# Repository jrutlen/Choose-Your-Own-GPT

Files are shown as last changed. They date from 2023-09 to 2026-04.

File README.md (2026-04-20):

# Choose Your Own GPT

Choose Your Own GPT is a seemingly analog device without any screens or visible digital elements. Spinning the physical dials to select characters and a story setting and then hitting the large arcade 'go' button, the built-in printer will spit out a Choose Your Own Adventure type story on the built-in receipt printer.

## Features

- Built-in 58mm thermal printer to dispense stories on demand
- Designed to be printable on 200mm² 3D printers
- Top dials can be snapped off of the main PCB to allow modification to any size
- Optional 4th dial can be added to increase story objects or add an additional element (talk like a pirate, etc.)
- Support for e-ink display (untested)
- Over-the-air (OTA) firmware updates via the web portal
- Import/export configuration as JSON

## Hardware Requirements

- ESP32 development board
- 58mm thermal printer (connected to ESP32 Serial2: RX=16, TX=17)
- Adafruit NeoPixel LEDs (WaitEnd ring: 13 LEDs on pin 26; Go button: 3 LEDs on pin 33)
- Arcade-style buttons with LEDs (Red: pin 27, Blue: pin 12, Green: pin 2, Yellow: pin 15)
- Rotary dials wired to input matrix (see PCB directory for schematic)
- 3D-printed enclosure (STL files in the `STLs` directory)
- Bill of materials in `Bill of Materials.csv`

## Building and Flashing

This project uses [PlatformIO](https://platformio.org/). All library dependencies are declared in `ChooseYourOwnGPT/platformio.ini` and are fetched automatically on first build.

1. Install [PlatformIO IDE](https://platformio.org/install) or the PlatformIO CLI.
2. Open the `ChooseYourOwnGPT` folder as a PlatformIO project.
3. Build and upload to the ESP32:
   ```
   pio run --target upload
   ```
4. You do **not** need to add your API key to the code before uploading — it is set via the web portal after the device is running.

### Library Dependencies

| Library | Version |
|---|---|
| Adafruit NeoPixel | 1.12.4 |
| Adafruit Thermal Printer | 1.4.1 |
| NetWizard | 1.2.0 |
| ArduinoJson | 7.3.1 |

### Building with GitHub Actions

A workflow (`.github/workflows/build.yml`) automatically builds the firmware on every push or pull request to `main`/`master` that touches `ChooseYourOwnGPT/` or the workflow file itself. No local toolchain is required to produce a flashable binary.

**What the workflow does:**
1. Checks out the repository.
2. Installs PlatformIO via `pip`.
3. Runs `pio run` inside `ChooseYourOwnGPT/`.
4. Uploads the compiled binaries as a `firmware` artifact:
   - `firmware.bin` — application image
   - `bootloader.bin` — ESP32 bootloader
   - `partitions.bin` — partition table

**Downloading the artifact:**
1. Go to the **Actions** tab of the repository on GitHub.
2. Click the latest successful **Build Firmware** run.
3. Scroll to the **Artifacts** section at the bottom and download `firmware`.
4. Unzip the archive to get the `.bin` files.

**Flashing the downloaded firmware:**

To flash from scratch (first time or full reflash), use `esptool.py`:
```
esptool.py --chip esp32 --baud 921600 \
  write_flash \
  0x1000  bootloader.bin \
  0x8000  partitions.bin \
  0x10000 firmware.bin
```

To update an already-running device, use the OTA firmware update in the web portal — see [OTA Firmware Update](#ota-firmware-update) below.

## First-Time Setup

1. Power on the device. It will start a Wi-Fi access point named **`ChooseYourOwnGPT`** with the password **`itMightBeMagic`**.
2. Connect to that network from your phone or computer.
3. A captive portal will open automatically (or navigate to `http://192.168.4.1`).
4. Enter your home Wi-Fi credentials and save. The device will reboot and connect to your network.

## Configuration

Once the device is connected to your Wi-Fi network, open a browser and go to:

```
http://<device-ip>/config
```

The device IP is printed to the serial console on connection. The configuration portal lets you adjust all settings without reflashing.

### General Settings

| Setting | Description |
|---|---|
| **OpenAI API Key** | Your `sk-…` key from [platform.openai.com](https://platform.openai.com/api-keys). Stored on the device only — never sent anywhere except the OpenAI API. |
| **OpenAI Model** | The model to use for story generation (default: `gpt-4o`). |
| **Hyphenate long words** | When enabled, words that are too long for a line are broken with a hyphen instead of overflowing. |

### Character Names (Small Dial)

Up to **10** character names can be assigned to positions on the small dial. Each position corresponds to a dial setting (0–9). Names can include relationship context (e.g. `"Mia (a 7-year-old girl)"`), which is passed directly to the story prompt.

### Adventure Destinations (Large Dial)

Up to **16** adventure destinations can be assigned to positions on the large dial. Each entry is a sentence fragment appended to the story prompt (e.g. `" who go on an adventure in the Amazon Rainforest."`).

### Story Prompts

These fields control the text sent to the OpenAI API at each stage of the story:

| Field | Description |
|---|---|
| **Story Prompt** | Opening prompt prepended before the selected character names. |
| **Instructions** | Instructions appended after the adventure destination (formatting rules, chapter length, button options, etc.). |
| **Surprise Ending Prompt** | Sent when the red button is pressed to request an unexpected ending. |
| **Blue Button – Continue** | Message sent when the blue button is pressed to continue the story. |
| **Blue Button – Final Chapter** | Message sent when the blue button is pressed in the final chapter. |
| **Yellow Button – Continue** | Message sent when the yellow button is pressed to continue the story. |
| **Yellow Button – Final Chapter** | Message sent when the yellow button is pressed in the final chapter. |

### Import / Export

Use the **Export Settings JSON** button to download all current settings as a `cyogpt-config.json` file. Use **Import Settings JSON** to restore or share a configuration.

### OTA Firmware Update

The `/config` portal includes a firmware update section. Select a compiled `.bin` file (from `pio run` build output) and click **Upload Firmware**. The device will reboot automatically after a successful update.

## Usage

1. Power on the device and wait for it to connect to Wi-Fi (the LEDs will indicate status).
2. Spin the **small dial** to select a character and the **large dial** to choose an adventure destination.
3. Press the **green Go button** to generate a story. The printer will output the first chapter.
4. At the end of each chapter, press the **blue** or **yellow** button to choose how the story continues.
5. Press the **red button** at any point to trigger a surprise ending.
6. After the final (5th) chapter, the story is complete. Set the dials and press Go to start a new story.

## Related

Build log with photos

[Hackaday.io](https://hackaday.io/project/192751-choose-your-own-gpt)

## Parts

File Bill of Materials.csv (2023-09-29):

Designator | Quantity | Designation
1,20 | 2 | PinSocket_1x19_P2.54mm_Vertical
D1-D12 | 12 | LED 3mm
D13-D32 | 20 | 1N4148
J1,J3,J13 | 3 | JST_XH_B3B-XH-A_1x03_P2.50mm_Vertical
J2,J4,J5,J6,J7,J8,J9,J10,J11,J12 | 10 | JST_XH_B2B-XH-A_1x02_P2.50mm_Vertical
J14 | 1 | JST_XH_B5B-XH-A_1x05_P2.50mm_Vertical
Q1-Q7 | 7 | 2N2222
R1,R3,R5 | 3 | 22Ω
R2,R11,R16 | 3 | 390Ω
R4,R6,R12,R14 | 4 | 1.7kΩ
R13,R15,R17 | 3 | 4.7kΩ
R7-R10 | 4 | Button LED Resistors (Optional - Bridge JP1&JP2 to bypass)
SW1-SW3 | 3 | Nidec_Copal_SH-7010C
SW5-SW8 | 4 | Magnetic Reed Switch (Optional)

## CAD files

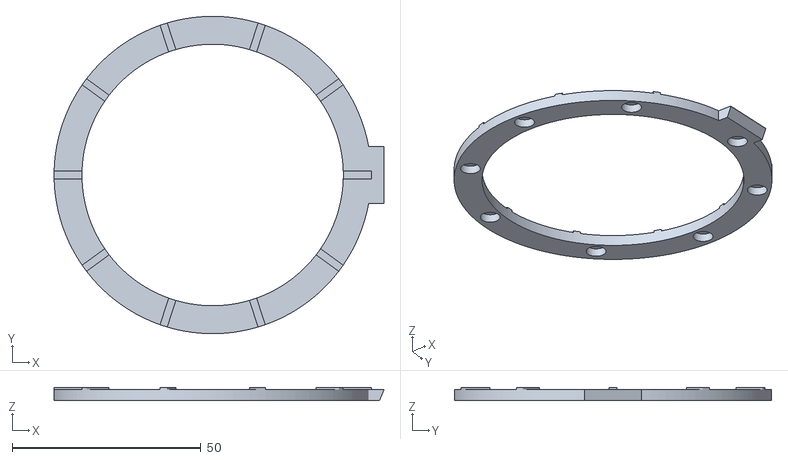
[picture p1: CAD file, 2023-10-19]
STLs/Ring Right Raised.stl
87.4 x 84.0 x 3.50

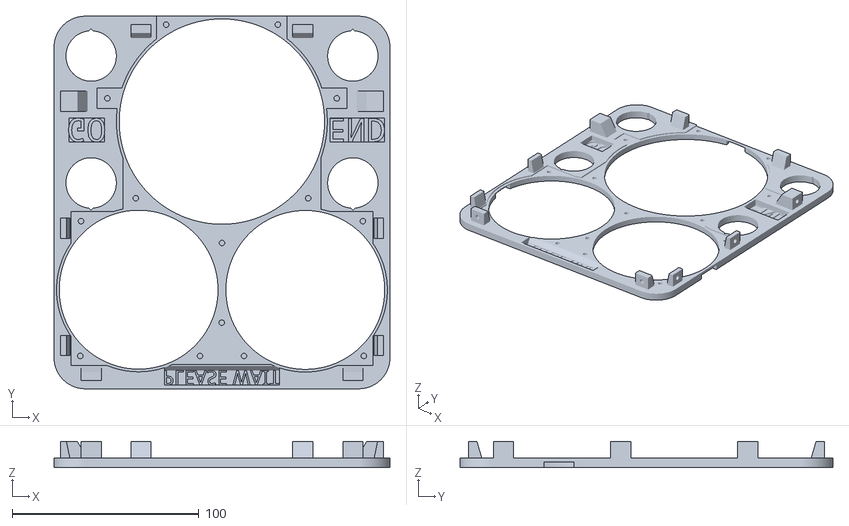
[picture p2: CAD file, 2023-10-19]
STLs/Front Panel Frame.stl
180.0 x 199.6 x 14.0

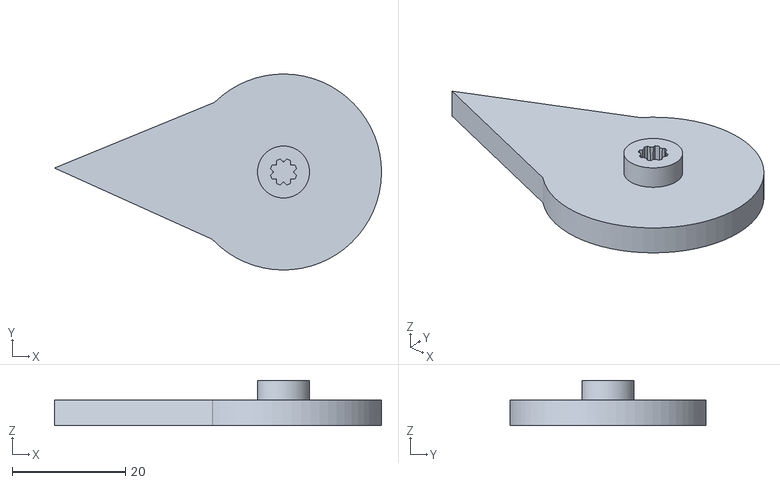
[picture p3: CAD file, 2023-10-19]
STLs/Dial Large.stl
57.8 x 34.6 x 8.00

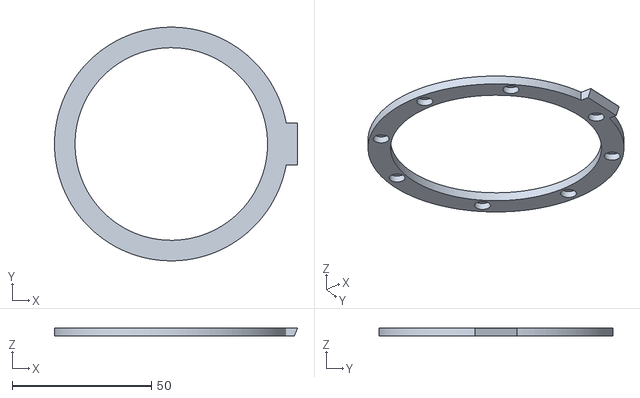
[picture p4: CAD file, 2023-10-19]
STLs/Ring Right Flat.stl
87.4 x 84.0 x 3.00

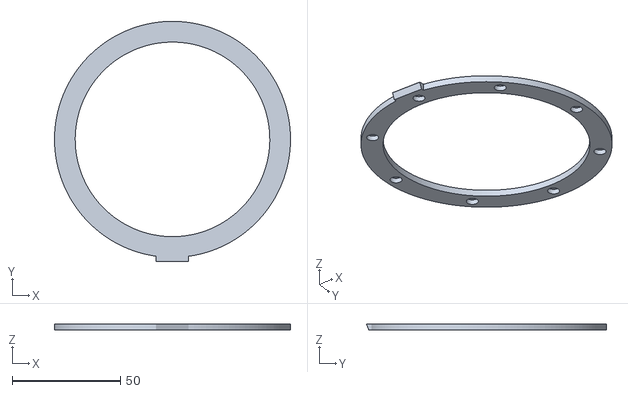
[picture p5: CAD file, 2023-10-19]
STLs/Ring Bottom Flat.stl
109.0 x 110.9 x 3.00

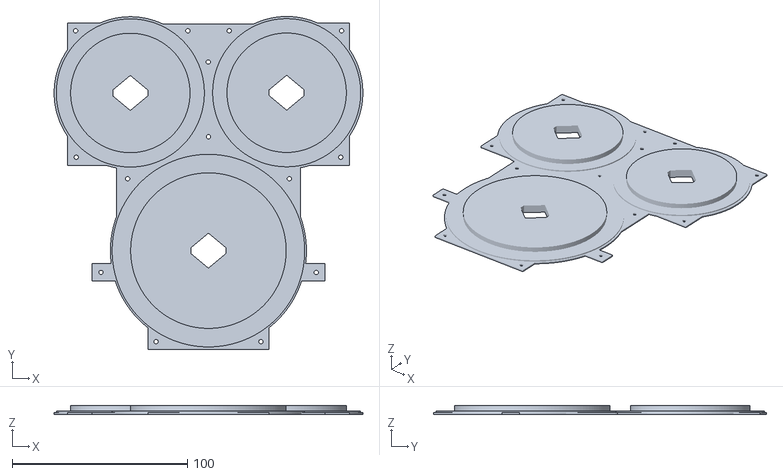
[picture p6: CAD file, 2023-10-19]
STLs/Front Panel Insert.stl
176.3 x 190.2 x 5.00

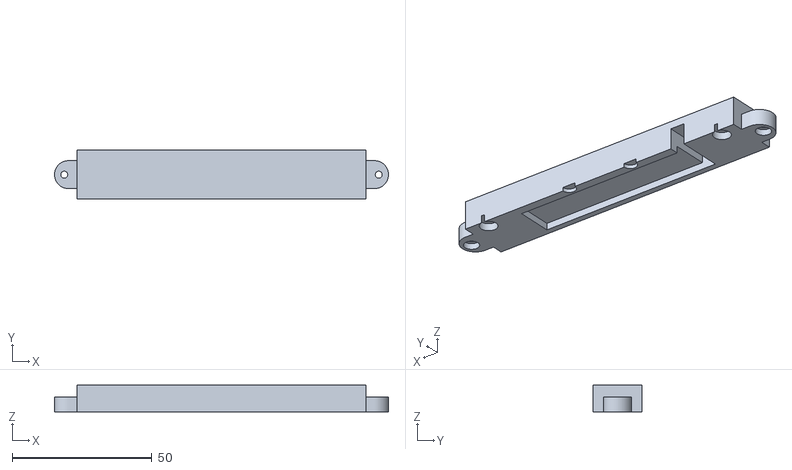
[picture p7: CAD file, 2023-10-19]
STLs/Bridge Insert.stl
119.6 x 17.6 x 9.58

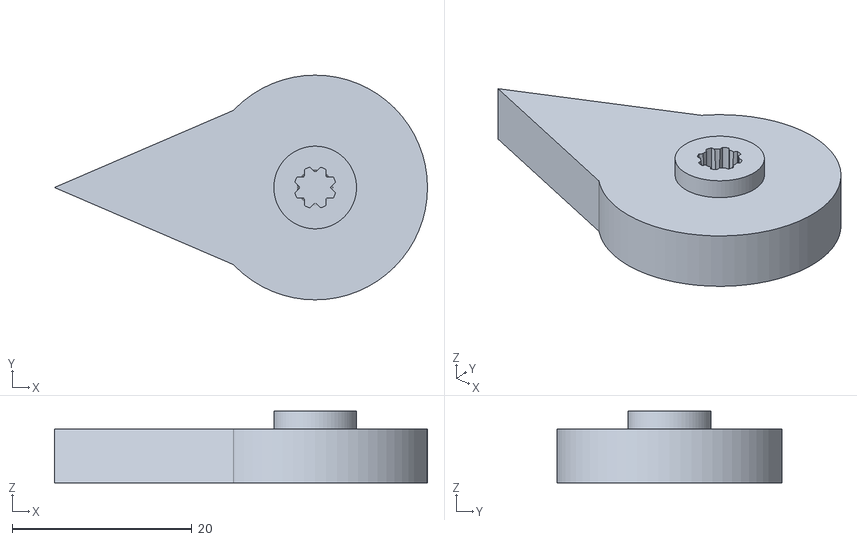
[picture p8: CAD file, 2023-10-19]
STLs/Dial Small.stl
41.5 x 25.0 x 8.00

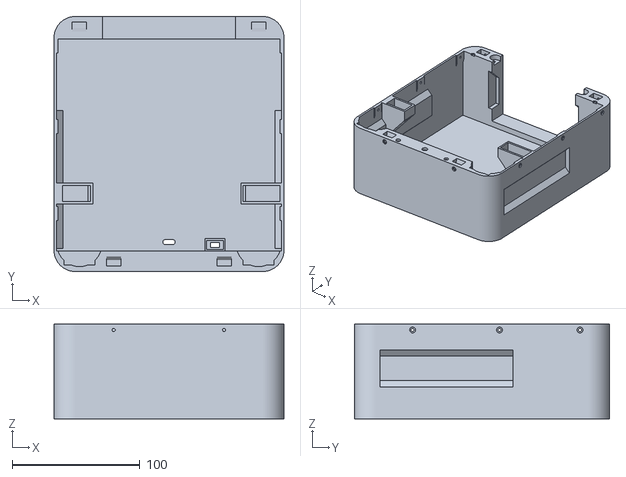
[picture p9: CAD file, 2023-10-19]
STLs/Body.stl
180.0 x 199.6 x 74.0

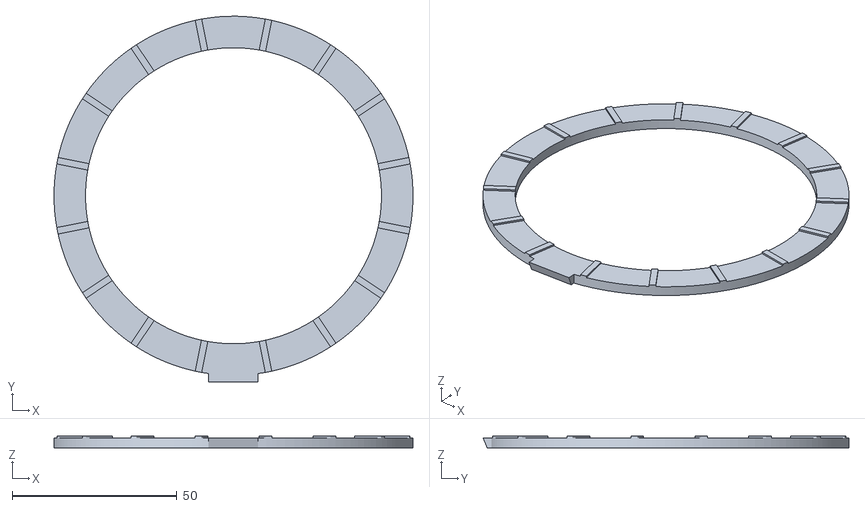
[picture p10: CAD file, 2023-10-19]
STLs/Ring Bottom Raised.stl
109.0 x 110.9 x 3.50

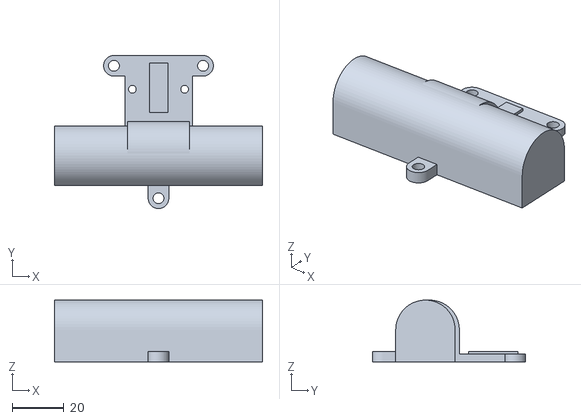
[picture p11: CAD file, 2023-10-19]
STLs/18650 Holder.stl
80.5 x 59.2 x 23.9

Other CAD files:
STLs/Ring Left Raised.stl
STLs/Ring Left Flat.stl
STLs/Body USB Only.stl

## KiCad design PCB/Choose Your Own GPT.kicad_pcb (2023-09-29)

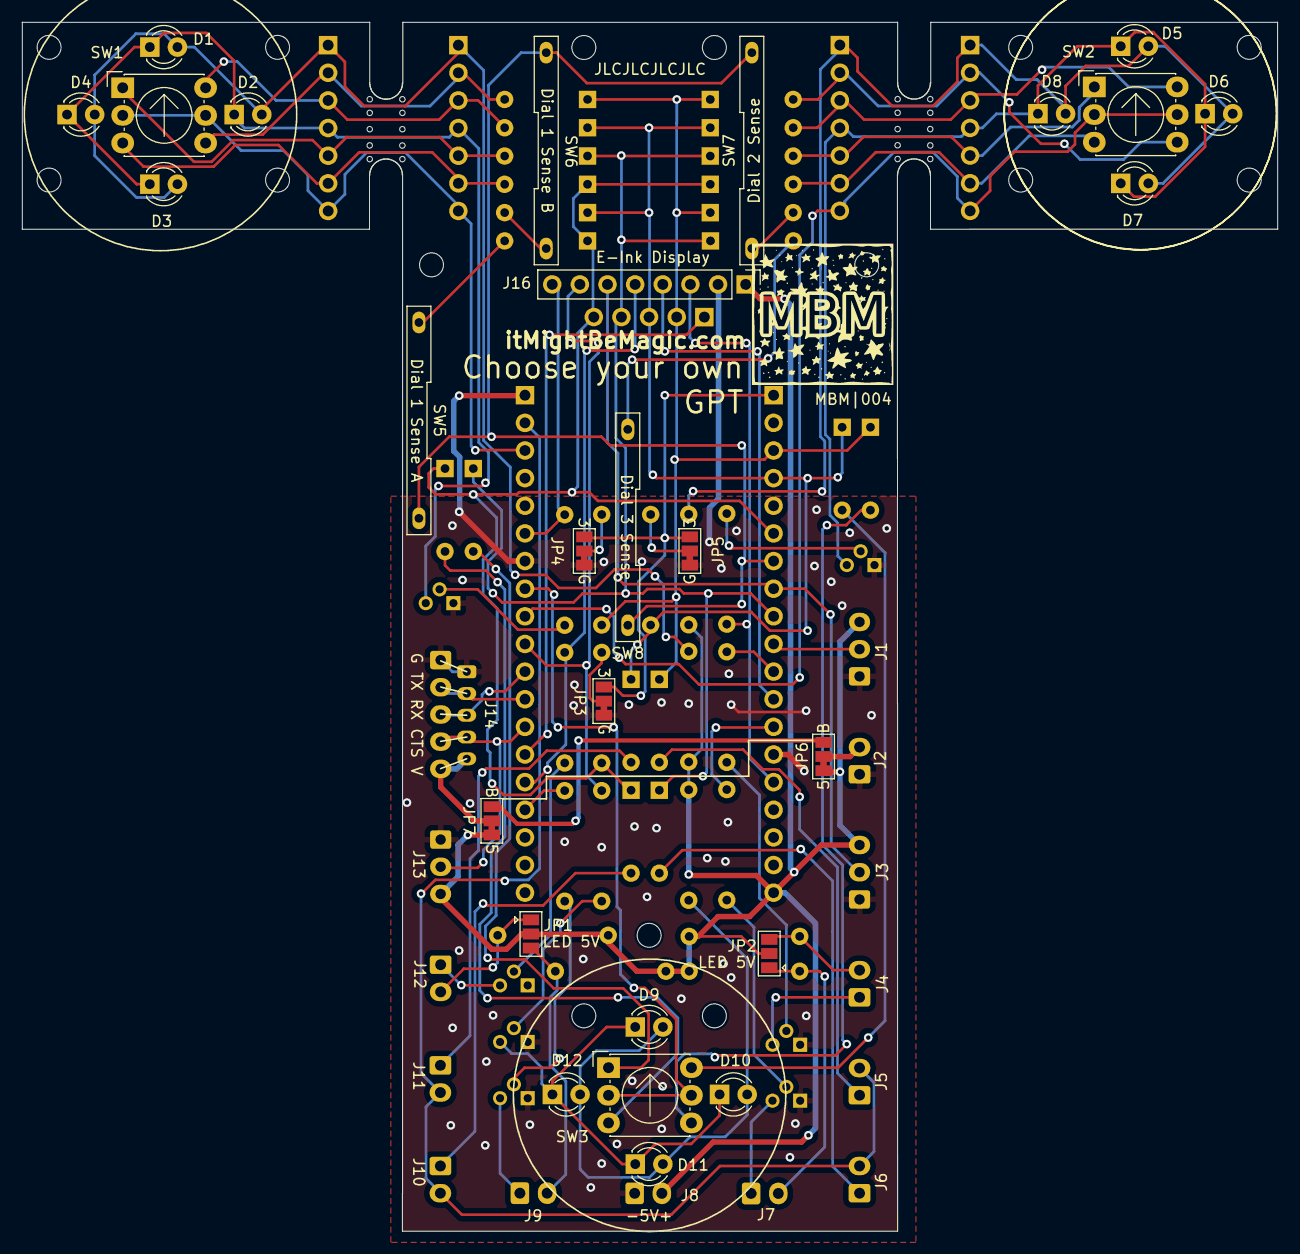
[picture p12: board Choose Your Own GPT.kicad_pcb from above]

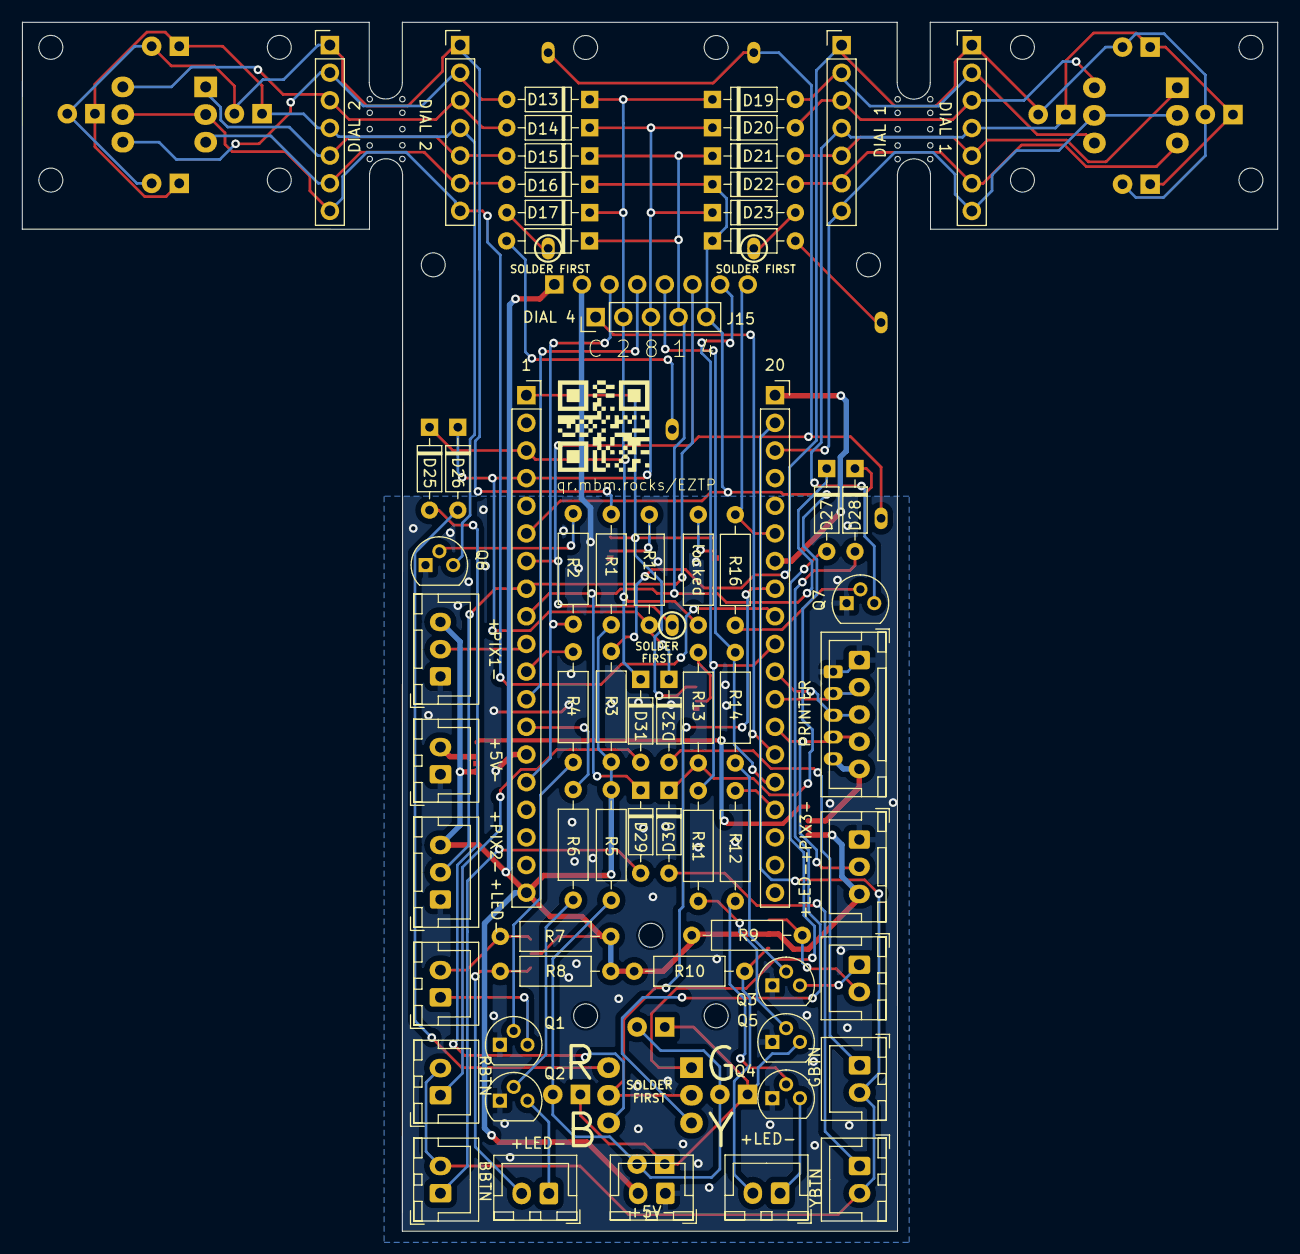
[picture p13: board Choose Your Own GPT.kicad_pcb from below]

Board: 2 copper layers, 115.4 x 111.1 mm, 97 parts (67 on the bottom side), 35 nets.

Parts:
1, 20: PinSocket_1x19_P2.54mm_Vertical
D1, D2, D3, D4, D5, D6, D7, D8, D9, D10, D11, D12: LED_D3.0mm
D13, D14, D15, D16, D17, D18, D19, D20, D21, D22, D23, D24, D25, D26, D27, D28, D29, D30, D31, D32: D_DO-35_SOD27_P7.62mm_Horizontal
DIAL 1, DIAL 1#2, DIAL 2, DIAL 2#2: PinHeader_1x07_P2.54mm_Vertical
J1, J3, J13: JST_XH_B3B-XH-A_1x03_P2.50mm_Vertical
J2, J4, J5, J6, J7, J8, J9, J10, J11, J12: JST_XH_B2B-XH-A_1x02_P2.50mm_Vertical
J14: JST_PH_B5B-PH-K_1x05_P2.00mm_Vertical
J14#2: JST_XH_B5B-XH-A_1x05_P2.50mm_Vertical
J15: PinHeader_1x05_P2.54mm_Vertical
J16: PinHeader_1x08_P2.54mm_Vertical
JP1, JP2: SolderJumper-3_P1.3mm_Open_Pad1.0x1.5mm
JP3, JP4: SolderJumper-3_P1.3mm_Bridged12_Pad1.0x1.5mm_NumberLabels
JP5, JP6, JP7: SolderJumper-3_P1.3mm_Bridged12_Pad1.0x1.5mm_Numb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; SolderJumper-3_P1.3mm_Bridged12_Pad1.0x1.5mm_NumberLabels
MBM|004: MBM Logo
Q1, Q2, Q3, Q4, Q5, Q6, Q7: TO-92
R1, R3, R5: 22; R_Axial_DIN0207_L6.3mm_D2.5mm_P10.16mm_Horizontal
R2, R11, R16: 390; R_Axial_DIN0207_L6.3mm_D2.5mm_P10.16mm_Horizontal
R4, R6, R12, R14: 1.7k; R_Axial_DIN0207_L6.3mm_D2.5mm_P10.16mm_Horizontal
R7, R8, R9, R10: R_Axial_DIN0207_L6.3mm_D2.5mm_P10.16mm_Horizontal
R13, R17: 4.7k; R_Axial_DIN0207_L6.3mm_D2.5mm_P10.16mm_Horizontal
SW1, SW2, SW3: Nidec_Copal_SH-7010C
SW5, SW6, SW7, SW8: Magnetic Reed Switch
locked: 4.7k; R_Axial_DIN0207_L6.3mm_D2.5mm_P10.16mm_Horizontal
mouse-bite-3mm-slot, mouse-bite-3mm-slot#2: VAL**; My MouseBite
qr.mbm.rocks/EZTP: LOGO

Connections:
3v3: 1.1, JP3.3, JP4.3, JP5.3
5V: 1.19, J1.3, J2.2, J3.3, J8.2, J13.3, J14.5, J14#2.5, J16.1, JP1.2, JP2.2, JP6.1, JP6.2, JP7.1, JP7.2, R1.2, R3.2, R5.1, R7.2, R8.2, R9.1, R10.1
BLED: 1.12, Q2.2, R6.1, R6.2
BLL-: J7.1, Q2.3
BTNC: 20.23, J5.2, J6.2, J10.2, J11.2
D1C: 20.22, DIAL 1.7, DIAL 1#2.7, SW1.C
D1GND: D1.1, D2.1, D3.1, D4.1, DIAL 1.4, DIAL 1#2.4, Q7.3
D1LED: 20.21, J16.BUSY, Q7.2, R16.1, R16.2
D2C: 20.18, DIAL 2.7, DIAL 2#2.7, SW2.C
D2GND: D5.1, D6.1, D7.1, D8.1, DIAL 2.4, DIAL 2#2.4, Q6.3
D2LED: 1.13, J16.MOSI, Q6.2, R2.1, R2.2
D3C: 20.19, SW3.C
D3GND: D9.1, D10.1, D11.1, D12.1, Q5.3
D3LED: 20.5, J16.RST, Q5.2, R11.1, R11.2
D3SEN: 1.14, J16.SCK
D4C: 20.0, J15.1
DSC: 1.32, SW5.2, SW6.2, SW7.2, SW8.2
GLED: 20.15, J16.CS, Q3.2, R14.1, R14.2
GND: 20.1, 20.7, J1.1, J2.1, J3.1, J8.1, J13.1, J14.1, J14#2.1, J16.2, JP3.1, JP4.1, JP5.1, Q1.1, Q2.1, Q3.1, Q4.1, Q5.1, Q6.1, Q7.1
GNL-: J12.1, Q3.3
JUMP: JP6.3, JP7.3
LED+: D1.2, D2.2, D3.2, D5.2, D6.2, D7.2, D9.2, D10.2, D11.2, DIAL 1.1, DIAL 1#2.1, DIAL 2.1, DIAL 2#2.1, J4.2, J7.2, J9.2, J12.2, JP1.1, JP1.3, JP2.1, JP2.3, R1.1, R3.1, R5.2, R7.1, R8.1, R9.2, R10.2
NEO1: 1.26, J1.2
NEO2: 1.33, J3.2, J16.DC
NEO3: 20.4, J13.2, J14.4, J14#2.4
RDL-: J4.1, Q1.3
RLED: 1.27, Q1.2, R4.1, R4.2
RX2: 20.17, J14.3, J14#2.3
SEL1: 1.25, D15.1, D15.2, D18.1, D18.2, D21.1, D21.2, D27.1, D27.2, D29.1, D29.2, DIAL 1.5, DIAL 1#2.5, DIAL 2.5, DIAL 2#2.5, J6.1, J15.4, SW1.1, SW2.1, SW3.1, SW8.1
SEL2: 1.36, D13.1, D13.2, D17.1, D17.2, D19.1, D19.2, D25.1, D25.2, D31.1, D31.2, DIAL 1.2, DIAL 1#2.2, DIAL 2.2, DIAL 2#2.2, J5.1, J15.2, JP4.2, SW1.2, SW2.2, SW3.2, SW7.1, locked.1, locked.2
SEL4: 1.35, D16.1, D16.2, D22.1, D22.2, D24.1, D24.2, D28.1, D28.2, D30.1, D30.2, DIAL 1.6, DIAL 1#2.6, DIAL 2.6, DIAL 2#2.6, J10.1, J15.5, JP3.2, R13.1, R13.2, SW1.4, SW2.4, SW3.4, SW5.1
SEL8: 1.39, D14.1, D14.2, D20.1, D20.2, D23.1, D23.2, D26.1, D26.2, D32.1, D32.2, DIAL 1.3, DIAL 1#2.3, DIAL 2.3, DIAL 2#2.3, J11.1, J15.3, JP5.2, R17.1, R17.2, SW1.8, SW2.8, SW3.8, SW6.1
TX2: 20.16, J14.2, J14#2.2
YLED: 20.2, Q4.2, R12.1, R12.2
YWL-: J9.1, Q4.3

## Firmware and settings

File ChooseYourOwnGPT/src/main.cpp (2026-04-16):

// WiFi and Web
#include <Arduino.h>
#include <WebServer.h>
#include <NetWizard.h>
#include <memory>

// Hardware
#include <Wire.h>
#include <Adafruit_NeoPixel.h>
#include "Adafruit_Thermal.h"

// OpenAI API
#define SERVER_RESPONSE_WAIT_TIME (30 * 1000)
#include <ChatGPTuino.h>

// Configuration and Web Portal
#include "config.h"
#include "web_portal.h"

// ─── OpenAI Chat ────────────────────────────────────────────
static const int TOKENS = 750;
static const int NUM_MESSAGES = 14;
std::unique_ptr<ChatGPTuino> chat = std::make_unique<ChatGPTuino>(TOKENS, NUM_MESSAGES);

// ─── Networking ─────────────────────────────────────────────
WebServer server(80);
NetWizard NW(&server);

// ─── Application Configuration ──────────────────────────────
AppConfig appConfig;

// ─── Hardware: LEDs ─────────────────────────────────────────
Adafruit_NeoPixel WaitEnd(13, 26, NEO_GRB + NEO_KHZ800);
Adafruit_NeoPixel Go(3, 33, NEO_GRB + NEO_KHZ800);

// ─── Hardware: Thermal Printer ──────────────────────────────
Adafruit_Thermal printer(&Serial2, 4);

// ─── Pin Definitions: Button LEDs ───────────────────────────
static const int PIN_LED_RED    = 27;
static const int PIN_LED_BLUE   = 12;
static const int PIN_LED_GREEN  = 2;
static const int PIN_LED_YELLOW = 15;

// ─── Pin Definitions: Dial LEDs ─────────────────────────────
static const int PIN_DIAL_LED1 = 21;
static const int PIN_DIAL_LED2 = 13;
static const int PIN_DIAL_LED3 = 5;

// ─── Pin Definitions: Input Matrix Columns ──────────────────
static const int PIN_SCAN_1 = 25;  // Dial 3
static const int PIN_SCAN_2 = 36;  // Dial 2
static const int PIN_SCAN_4 = 35;  // Dial 1A
static const int PIN_SCAN_8 = 39;  // Dial 1B

// ─── Pin Definitions: Input Matrix Rows ─────────────────────
static const int PIN_COM_D0  = 22;
static const int PIN_COM_D1  = 18;
static const int PIN_COM_D2  = 19;
static const int PIN_COM_BTN = 23;
static const int PIN_COM_MAG = 32;

// ─── WaitEnd LED Segments ───────────────────────────────────
static const int WAIT_START  = 0;
static const int WAIT_LENGTH = 9;
static const int END_START   = 9;
static const int END_LENGTH  = 4;

// ─── PWM Configuration ─────────────────────────────────────
static const int PWM_FREQ         = 5000;
static const int PWM_CHANNEL_DIAL = 0;
static const int PWM_CHANNEL_BTN  = 1;
static const int PWM_RESOLUTION   = 8;

// ─── Matrix Scanning ───────────────────────────────────────
static const int SCAN_DELAY_MS = 100;
static const int DIAL_READ_DELAY_MS = 10;  // Settle time between sequential dial reads
unsigned long lastScanTime = 0;

int  dial[3]     = {0, 0, 0};
int  lastDial[3] = {0, 0, 0};
bool dialSet[3]  = {false, false, false};
bool button[4]   = {false, false, false, false};

// ─── State Machine ─────────────────────────────────────────
//  0 = boot
//  1 = connecting to WiFi
//  2 = connected to WiFi
//  3 = initializing (reading initial dial positions)
//  4 = ready / waiting for dial input
//  5 = story requested (first chapter transition)
//  6 = generating first chapter
//  8 = generating next chapter
//  9 = story printed, waiting for button decision
// 11 = story complete
int state = 0;
int currentChapter = 1;
static const int MAX_CHAPTERS = 5;
int decision = 0;  // 0 = none, 1 = red (surprise), 2 = blue, 3 = yellow

// ─── LED Fade Animation ────────────────────────────────────
int fade = 0;
int slowFade = 0;
unsigned long lastFadeTime = 0;
unsigned long lastSlowFadeTime = 0;
int fadeDirection = 1;
int slowFadeDirection = 1;
static const unsigned long FADE_SPEED_MS      = 1;
static const unsigned long SLOW_FADE_SPEED_MS = 10;
static const int MAX_SLOW_FADE = 100;

// ─── Forward Declarations ──────────────────────────────────
void onConfigSaved();
void printTitle(int chapterNumber);
void printWrapped(const char *message);
void sendToPrint(const char *message);
int  checkDial(int dialNumber);
void checkButton();
void fadeCalc();
void slowFadeCalc();
void resetHardwareState();
void initChatIfConfigured();

// ─── Chat Initialization Helper ────────────────────────────
void initChatIfConfigured() {
  if (appConfig.apiKey.length() > 0) {
    chat->init(appConfig.apiKey.c_str(), appConfig.model.c_str());
    Serial.println("Chat initialized");
  } else {
    Serial.println("Chat NOT initialized - configure API key at /config");
  }
}

// ─── Configuration Callback ────────────────────────────────
void onConfigSaved() {
  initChatIfConfigured();
}

// ─── Setup ─────────────────────────────────────────────────
void setup() {
  state = 1;
  WaitEnd.clear();
  WaitEnd.fill(WaitEnd.Color(0, 0, 255), WAIT_START, WAIT_LENGTH);
  WaitEnd.show();

  Serial.begin(115200);
  delay(1000);

  // Load persistent configuration from NVS
  configLoad(appConfig);
  Serial.printf("Config loaded. Model: %s\n", appConfig.model.c_str());
  if (appConfig.apiKey.length() == 0) {
    Serial.println("WARNING: No API key configured. Visit /config after WiFi setup.");
  }

  // WiFi provisioning via NetWizard
  NW.setStrategy(NetWizardStrategy::BLOCKING);

  NW.onConnectionStatus([](NetWizardConnectionStatus status) {
    const char *statusStr = "Unknown";
    switch (status) {
      case NetWizardConnectionStatus::DISCONNECTED:      statusStr = "Disconnected"; break;
      case NetWizardConnectionStatus::CONNECTING:        statusStr = "Connecting"; break;
      case NetWizardConnectionStatus::CONNECTED:         statusStr = "Connected"; break;
      case NetWizardConnectionStatus::CONNECTION_FAILED: statusStr = "Connection Failed"; break;
      case NetWizardConnectionStatus::CONNECTION_LOST:   statusStr = "Connection Lost"; break;
      case NetWizardConnectionStatus::NOT_FOUND:         statusStr = "Not Found"; break;
      default: break;
    }
    Serial.printf("WiFi status: %s\n", statusStr);

    if (status == NetWizardConnectionStatus::CONNECTED) {
      Serial.printf("Local IP: %s\n", NW.localIP().toString().c_str());
      Serial.printf("Config portal: http://%s/config\n", NW.localIP().toString().c_str());
      initChatIfConfigured();
      // (Re)start the web server every time WiFi connects or reconnects.
      // This is safe here because the lwIP stack is up by the time this
      // callback fires.  It also handles the reconnect case where the
      // server socket was lost after a WiFi drop.
      server.begin();
    }
  });

  NW.onPortalState([](NetWizardPortalState portalState) {
    const char *stateStr = "Unknown";
    switch (portalState) {
      case NetWizardPortalState::IDLE:                   stateStr = "Idle"; break;
      case NetWizardPortalState::CONNECTING_WIFI:        stateStr = "Connecting to WiFi"; break;
      case NetWizardPortalState::WAITING_FOR_CONNECTION: stateStr = "Waiting for Connection"; break;
      case NetWizardPortalState::SUCCESS:                stateStr = "Success"; break;
      case NetWizardPortalState::FAILED:                 stateStr = "Failed"; break;
      case NetWizardPortalState::TIMEOUT:                stateStr = "Timeout"; break;
      default: break;
    }
    Serial.printf("Portal state: %s\n", stateStr);
  });

  // Register config routes BEFORE autoConnect so they survive the captive-portal
  // lifecycle: NetWizard's _stopHTTP() only removes its own tracked handlers
  // (_index_handler, _status_handler, …), never the app's routes registered here.
  webPortalSetup(server, appConfig, onConfigSaved);

  NW.autoConnect("ChooseYourOwnGPT", "itMightBeMagic");
  // server.begin() is called inside the onConnectionStatus CONNECTED callback
  // above, which fires during autoConnect() once WiFi is up and the lwIP stack
  // is initialised.  It is also called on any subsequent reconnection.

  if (NW.isConfigured()) {
    Serial.println("WiFi configured");
  } else {
    Serial.println("WiFi not configured");
  }

  // Configure button LED pins
  pinMode(PIN_LED_RED, OUTPUT);
  pinMode(PIN_LED_BLUE, OUTPUT);
  pinMode(PIN_LED_GREEN, OUTPUT);
  pinMode(PIN_LED_YELLOW, OUTPUT);
  digitalWrite(PIN_LED_RED, LOW);
  digitalWrite(PIN_LED_BLUE, LOW);
  digitalWrite(PIN_LED_GREEN, LOW);
  digitalWrite(PIN_LED_YELLOW, LOW);

  // Configure matrix input pins
  pinMode(PIN_SCAN_1, INPUT);
  pinMode(PIN_SCAN_2, INPUT);
  pinMode(PIN_SCAN_4, INPUT);
  pinMode(PIN_SCAN_8, INPUT);

  // Configure matrix output pins
  pinMode(PIN_COM_D0, OUTPUT);
  pinMode(PIN_COM_D1, OUTPUT);
  pinMode(PIN_COM_D2, OUTPUT);
  pinMode(PIN_COM_BTN, OUTPUT);
  pinMode(PIN_COM_MAG, OUTPUT);

  state = 2;

  // Turn off all LEDs
  Go.clear();
  WaitEnd.clear();
  Go.fill(Go.Color(0, 0, 0), 0, 3);
  WaitEnd.fill(WaitEnd.Color(0, 0, 0), WAIT_START, WAIT_LENGTH);
  WaitEnd.fill(WaitEnd.Color(0, 0, 0), END_START, END_LENGTH);
  Go.show();
  WaitEnd.show();

  // Initialize thermal printer
  Serial2.begin(9600, SERIAL_8N1, 16, 17);
  printer.begin();
  printer.reset();
  //printer.wake();
  printer.setSize('S');
  printer.setDefault();

  // Print device name on boot (original logo style: medium, centred, bold inverse)
  printer.setSize('M');
  printer.justify('C');
  printer.boldOn();
  printer.inverseOn();
  printer.println("-Choose-Your-Own-GPT-");
  printer.boldOff();
  printer.inverseOff();
  printer.justify('L');
  printer.setSize('S');
  printer.feed(2);

  // Configure PWM for dial LEDs
  ledcAttachChannel(PIN_DIAL_LED1, PWM_FREQ, PWM_RESOLUTION, PWM_CHANNEL_DIAL);
  ledcAttachChannel(PIN_DIAL_LED2, PWM_FREQ, PWM_RESOLUTION, PWM_CHANNEL_DIAL);
  ledcAttachChannel(PIN_DIAL_LED3, PWM_FREQ, PWM_RESOLUTION, PWM_CHANNEL_DIAL);

  state = 3;
}

// ─── Helper Functions ──────────────────────────────────────

void printTitle(int chapterNumber) {
  //printer.wake();
  printer.setSize('L');
  printer.justify('C');
  printer.boldOn();
  printer.println("Chapter " + String(chapterNumber));
  printer.boldOff();
  printer.justify('L');
  printer.setSize('S');
  printer.feed(2);
}

void printWrapped(const char *message) {
  const int LINE_WIDTH = 32;
  // Minimum chars available to make hyphenation worthwhile: space + 1 char + '-'
  const int MIN_HYPHENATION_SPACE = 3;
  if (!message) return;

  bool hyphenate = appConfig.hyphenate;
  String remaining = String(message);
  String currentLine = "";
  int pos = 0;
  int len = remaining.length();

  auto flushLine = [&]() {
    int pad = LINE_WIDTH - (int)currentLine.length();
    for (int i = 0; i < pad; i++) currentLine += ' ';
    printer.println(currentLine);
    currentLine = "";
  };

  // Place a word onto the current line, hyphenating mid-word if enabled.
  auto placeWord = [&](const String &word) {
    int wpos = 0;
    int wlen = word.length();
    while (wpos < wlen) {
      if (currentLine.length() == 0) {
        if (!hyphenate || (wlen - wpos) <= LINE_WIDTH) {
          // Whole remaining fragment fits, or hyphenation is off — just accept it
          currentLine = word.substring(wpos);
          wpos = wlen;
        } else {
          // Fragment exceeds a full line — break with hyphen at LINE_WIDTH-1
          currentLine = word.substring(wpos, wpos + LINE_WIDTH - 1) + '-';
          wpos += LINE_WIDTH - 1;
          flushLine();
        }
      } else {
        int space = LINE_WIDTH - (int)currentLine.length();
        // needed = 1 (space separator before word) + remaining fragment length
        int needed = 1 + (wlen - wpos);
        if (needed <= space) {
          // Word fits on the current line
          currentLine += ' ';
          currentLine += word.substring(wpos);
          wpos = wlen;
        } else if (hyphenate && space >= MIN_HYPHENATION_SPACE) {
          // Enough room for: space + at least 1 char + hyphen
          currentLine += ' ';
          currentLine += word.substring(wpos, wpos + space - 2);
          currentLine += '-';
          wpos += space - 2;
          flushLine();
        } else {
          // Flush current line and retry on a fresh line
          flushLine();
        }
      }
    }
  };

  while (pos < len) {
    // Skip leading spaces before the next word
    while (pos < len && remaining[pos] == ' ') pos++;
    if (pos >= len) break;

    if (remaining[pos] == '\n') {
      // Explicit newline forces a line break
      flushLine();
      pos++;
      continue;
    }

    // Collect the next word
    int wordStart = pos;
    while (pos < len && remaining[pos] != ' ' && remaining[pos] != '\n') pos++;
    String word = remaining.substring(wordStart, pos);

    placeWord(word);
  }

  // Flush any remaining text
  if (currentLine.length() > 0) {
    flushLine();
  }
}

void sendToPrint(const char *message) {
  if (!message) {
    Serial.println("sendToPrint: null message, skipping");
    return;
  }
  //printer.wake();
  printer.setSize('S');
  printWrapped(message);
  printer.feed(3);
}

int checkDial(int dialNumber) {
  // Activate the row common pin for the selected dial
  digitalWrite(PIN_COM_D0, dialNumber == 0 ? HIGH : LOW);
  digitalWrite(PIN_COM_D1, dialNumber == 1 ? HIGH : LOW);
  digitalWrite(PIN_COM_D2, dialNumber == 2 ? HIGH : LOW);
  digitalWrite(PIN_COM_BTN, LOW);
  digitalWrite(PIN_COM_MAG, LOW);

  // Read 4-bit value from column pins
  int value = 0;
  if (digitalRead(PIN_SCAN_1)) value += 1;
  if (digitalRead(PIN_SCAN_2)) value += 2;
  if (digitalRead(PIN_SCAN_4)) value += 4;
  if (digitalRead(PIN_SCAN_8)) value += 8;

  // Reset all row commons
  digitalWrite(PIN_COM_D0, LOW);
  digitalWrite(PIN_COM_D1, LOW);
  digitalWrite(PIN_COM_D2, LOW);

  return value;
}

void checkButton() {
  digitalWrite(PIN_COM_BTN, HIGH);
  digitalWrite(PIN_COM_D0, LOW);
  digitalWrite(PIN_COM_D1, LOW);
  digitalWrite(PIN_COM_D2, LOW);
  digitalWrite(PIN_COM_MAG, LOW);

  button[0] = digitalRead(PIN_SCAN_1);
  button[1] = digitalRead(PIN_SCAN_2);
  button[2] = digitalRead(PIN_SCAN_8);
  button[3] = digitalRead(PIN_SCAN_4);

  digitalWrite(PIN_COM_BTN, LOW);
}

void fadeCalc() {
  if (millis() - lastFadeTime > FADE_SPEED_MS) {
    lastFadeTime = millis();
    if (fade < 255 && fadeDirection == 1) {
      fade++;
    } else if (fade > 75 && fadeDirection == 0) {
      fade--;
    } else if (fade <= 75) {
      fadeDirection = 1;
      fade = 76;
    } else if (fade >= 255) {
      fadeDirection = 0;
      fade = 254;
    }
    ledcWriteChannel(PWM_CHANNEL_DIAL, fade);
  }
}

void slowFadeCalc() {
  if (millis() - lastSlowFadeTime > SLOW_FADE_SPEED_MS) {
    lastSlowFadeTime = millis();
    if (slowFade < MAX_SLOW_FADE && slowFadeDirection == 1) {
      slowFade++;
    } else if (slowFade > 0 && slowFadeDirection == 0) {
      slowFade--;
    } else if (slowFade == 0) {
      slowFadeDirection = 1;
    } else if (slowFade == MAX_SLOW_FADE) {
      slowFadeDirection = 0;
    }
    ledcWriteChannel(PWM_CHANNEL_BTN, slowFade);
  }
}

void resetHardwareState() {
  Go.clear();
  Go.show();
  WaitEnd.clear();
  WaitEnd.show();

  digitalWrite(PIN_LED_GREEN, LOW);
  digitalWrite(PIN_LED_YELLOW, LOW);
  digitalWrite(PIN_LED_RED, LOW);
  digitalWrite(PIN_LED_BLUE, LOW);

  digitalWrite(PIN_DIAL_LED1, LOW);
  digitalWrite(PIN_DIAL_LED2, LOW);
  digitalWrite(PIN_DIAL_LED3, LOW);

  dialSet[0] = false;
  dialSet[1] = false;
  dialSet[2] = false;

  ledcAttachChannel(PIN_DIAL_LED1, PWM_FREQ, PWM_RESOLUTION, PWM_CHANNEL_DIAL);
  ledcAttachChannel(PIN_DIAL_LED2, PWM_FREQ, PWM_RESOLUTION, PWM_CHANNEL_DIAL);
  ledcAttachChannel(PIN_DIAL_LED3, PWM_FREQ, PWM_RESOLUTION, PWM_CHANNEL_DIAL);

  currentChapter = 1;

  // Reset the chat session for the next story so the previous story's message
  // history is not included in the next API request.  Reassigning the
  // unique_ptr automatically destroys the old object and creates a fresh one
  // with _msgCount = 0.
  chat = std::make_unique<ChatGPTuino>(TOKENS, NUM_MESSAGES);
  initChatIfConfigured();
}

// ─── Clamped index helpers ─────────────────────────────────

static int clampIndex(int value, int maxCount) {
  if (maxCount <= 0) return 0;
  if (value >= maxCount) return maxCount - 1;
  return value;
}

// ─── Main Loop ─────────────────────────────────────────────
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

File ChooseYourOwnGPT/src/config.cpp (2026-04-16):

#include "config.h"
#include <Preferences.h>

static const char NVS_NAMESPACE[] = "cyogpt";

void configLoadDefaults(AppConfig &cfg) {
  cfg.apiKey = "";
  cfg.model = "gpt-4o";
  cfg.hyphenate = false;

  cfg.nameCount = 10;
  cfg.names[0] = "Aunt Lily (Mia and Zoe's aunt, married to Uncle Ray)";
  cfg.names[1] = "Mia (a 7-year-old girl, 5-year-old Zoe's sister)";
  cfg.names[2] = "Zoe (a 5-year-old girl, 7-year-old Mia's sister)";
  cfg.names[3] = "Grandma June (Mia and Zoe's grandmother, Dad's mom, the villain in the story)";
  cfg.names[4] = "Buddy (Uncle Ray and Aunt Lily's dog with floppy ears)";
  cfg.names[5] = "Dad (Mia and Zoe's dad)";
  cfg.names[6] = "Mom (Mia and Zoe's mom, Aunt Lily's sister)";
  cfg.names[7] = "Nana (Mia and Zoe's grandmother, Aunt Lily and Mom's mom)";
  cfg.names[8] = "Papa Joe (Mia and Zoe's grandfather, Aunt Lily and Mom's dad)";
  cfg.names[9] = "Uncle Ray (Mia and Zoe's uncle, married to Aunt Lily)";

  cfg.adventureCount = 16;
  cfg.adventures[0]  = " who go on an adventure in the Amazon Rainforest.";
  cfg.adventures[1]  = " who go on an adventure to a Robotic World.";
  cfg.adventures[2]  = " who go on adventure exploring secret caves.";
  cfg.adventures[3]  = " who go to a Magical School.";
  cfg.adventures[4]  = " who go on an adventure in an underground city.";
  cfg.adventures[5]  = " who go on a Time Travel adventure in a Tardis.";
  cfg.adventures[6]  = " who go on a Medieval Fantasy adventure.";
  cfg.adventures[7]  = " who go on a Arctic Expedition adventure.";
  cfg.adventures[8]  = " who go on a Jungle Safari adventure.";
  cfg.adventures[9]  = " who go on an underwater adventure.";
  cfg.adventures[10] = " who go on a Prehistoric Adventure.";
  cfg.adventures[11] = " who go on an adventure in the Enchanted Forest.";
  cfg.adventures[12] = " who go on a Pirate Adventure. Please tell the entire story in pirate speak.";
  cfg.adventures[13] = " who go on adventure in outer space. Make sure there are lasers and aliens.";
  cfg.adventures[14] = " who go on adventure in the African Savanna.";
  cfg.adventures[15] = " who get recruited to join the Superhero Academy.";

  cfg.storyPrompt = "Please write a simple outline for a 5 chapter choose your own adventure story. "
    "The first act should set up the story and provide a pivotal decision at the end that will "
    "completely change the course of the story. The second act should present a challenge and "
    "incorporate a choice that will come back in the 5th and final chapter. The third act should "
    "provide a false victory or twist. The fourth act should be the final push. The 5th and final "
    "act is the climax and resolution. The story is about ";

  cfg.instructions = "Once completed, please respond 'COMPLETED'. When I send the word 'Begin', "
    "respond with the first chapter. Each chapter should be approximately 180 words. End each "
    "chapter with exactly two options, 'yellow' or 'blue' to continue the story in the format "
    "'to do x, press the yellow button' or 'to do y, press the blue button'. At the end of each "
    "chapter you must present these two options. Don't include any chapter titles or numbers and "
    "use only basic punctuation like single quotes, commas, periods, new line, and exclamation "
    "points. Do not use markdown, asterisks, hash symbols, dashes at the start of lines, bold, "
    "italics, or any special formatting characters. Plain text only.";

  cfg.surpriseEnding  = "Write a surprise ending to the story that is different than either the blue or the yellow options.";
  cfg.blueContinue    = "Press the blue button.";
  cfg.blueComplete    = "Write the final chapter to the story. Push the blue button.";
  cfg.yellowContinue  = "Press the yellow button.";
  cfg.yellowComplete  = "Write the final chapter to the story. Push the yellow button.";
}

void configLoad(AppConfig &cfg) {
  configLoadDefaults(cfg);

  Preferences prefs;
  if (!prefs.begin(NVS_NAMESPACE, true)) {
    Serial.println("NVS: Could not open for reading, using defaults");
    return;
  }

  if (prefs.isKey("apiKey"))    cfg.apiKey   = prefs.getString("apiKey");
  if (prefs.isKey("model"))     cfg.model    = prefs.getString("model");
  if (prefs.isKey("hyphenate")) cfg.hyphenate = prefs.getBool("hyphenate");

  if (prefs.isKey("nameCnt")) {
    int count = prefs.getInt("nameCnt", cfg.nameCount);
    if (count > 0 && count <= MAX_NAMES) {
      cfg.nameCount = count;
      for (int i = 0; i < cfg.nameCount; i++) {
        char key[16];
        snprintf(key, sizeof(key), "name%d", i);
        if (prefs.isKey(key)) {
          cfg.names[i] = prefs.getString(key);
        }
      }
    }
  }

  if (prefs.isKey("advCnt")) {
    int count = prefs.getInt("advCnt", cfg.adventureCount);
    if (count > 0 && count <= MAX_ADVENTURES) {
      cfg.adventureCount = count;
      for (int i = 0; i < cfg.adventureCount; i++) {
        char key[16];
        snprintf(key, sizeof(key), "adv%d", i);
        if (prefs.isKey(key)) {
          cfg.adventures[i] = prefs.getString(key);
        }
      }
    }
  }

  if (prefs.isKey("prompt"))   cfg.storyPrompt    = prefs.getString("prompt");
  if (prefs.isKey("instruct")) cfg.instructions    = prefs.getString("instruct");
  if (prefs.isKey("surprise")) cfg.surpriseEnding  = prefs.getString("surprise");
  if (prefs.isKey("blueCont")) cfg.blueContinue    = prefs.getString("blueCont");
  if (prefs.isKey("blueComp")) cfg.blueComplete    = prefs.getString("blueComp");
  if (prefs.isKey("yelCont"))  cfg.yellowContinue  = prefs.getString("yelCont");
  if (prefs.isKey("yelComp"))  cfg.yellowComplete  = prefs.getString("yelComp");

  prefs.end();
  Serial.println("NVS: Configuration loaded");
}

void configSave(const AppConfig &cfg) {
  Preferences prefs;
  if (!prefs.begin(NVS_NAMESPACE, false)) {
    Serial.println("NVS: Could not open for writing");
    return;
  }

  prefs.putString("apiKey",   cfg.apiKey);
  prefs.putString("model",    cfg.model);
  prefs.putBool("hyphenate",  cfg.hyphenate);

  prefs.putInt("nameCnt", cfg.nameCount);
  for (int i = 0; i < cfg.nameCount; i++) {
    char key[16];
    snprintf(key, sizeof(key), "name%d", i);
    prefs.putString(key, cfg.names[i]);
  }

  prefs.putInt("advCnt", cfg.adventureCount);
  for (int i = 0; i < cfg.adventureCount; i++) {
    char key[16];
    snprintf(key, sizeof(key), "adv%d", i);
    prefs.putString(key, cfg.adventures[i]);
  }

  prefs.putString("prompt",   cfg.storyPrompt);
  prefs.putString("instruct", cfg.instructions);
  prefs.putString("surprise", cfg.surpriseEnding);
  prefs.putString("blueCont", cfg.blueContinue);
  prefs.putString("blueComp", cfg.blueComplete);
  prefs.putString("yelCont",  cfg.yellowContinue);
  prefs.putString("yelComp",  cfg.yellowComplete);

  prefs.end();
  Serial.println("NVS: Configuration saved");
}
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

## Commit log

2023-09-29 Initial Commit
    Added PCB files
    [Choose Your Own GPT-B_Cu.gbl, Choose Your Own GPT-B_Mask.gbs, Choose Your Own GPT-B_Paste.gbp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]
2023-09-29 Create Bill of Materials.csv
    [Bill of Materials.csv]
2023-10-19 Add 3D Files
    [18650 Holder.stl, Body USB Only.stl, Body.stl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]
2026-04-13 Add web configuration portal, remove MQTT, clean up codebase
    - Add config.h/config.cpp: Persistent configuration using ESP32 NVS (Preferences)
    with defaults for model, API key, names, adventures, and all prompts
    - Add web_portal.h/web_portal.cpp: Web-based config UI at /config with JSON API
    endpoints for get/save/reset configuration
    - Rewrite main.cpp: Remove unused MQTT parameters, remove credentials.h dependency,
    integrate config system, fix missing comma bug in adventureNames array,
    fix memory leak (malloc without free), add bounds checking for dial values,
    rename magic numbers to named constants, extract resetHardwareState(),
    use switch/case instead of if/else chain, clean up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
    [config.cpp, main.cpp]
2026-04-14 Fix /config not loading after WiFi connects
    Two bugs prevented the config page from being served:
    1. webPortalSetup() and server.begin() were called after NW.autoConnect().
    In the captive-portal path (first boot), NetWizard calls server.begin()
    internally, then WiFi.mode(WIFI_STA) tears down the AP interface.
    Because NetWizard leaves the internal _server handle non-null,
    the sketch's later server.begin() hits the early-return guard and is
    silently skipped — but the socket bound to the (now-gone) AP interface
    may be unusable on the STA network.
    Fix: register routes and start the server before autoConnect so the
    socket is live on INADDR_ANY before any interface chang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
    [main.cpp]
2026-04-14 Fix bootloop: move server.begin() after autoConnect
    Calling server.begin() before NW.autoConnect() (the previous fix) triggers
    lwIP's "Invalid mbox" assert crash-loop because the TCP/IP task mailbox does
    not exist until WiFi.begin() is called inside autoConnect.
    Fix: keep webPortalSetup() before autoConnect (routes registered here
    survive NetWizard's _stopHTTP() which only removes its own handlers), but
    move server.begin() back to after autoConnect so it runs only after the
    lwIP stack is initialised. In the captive-portal path NetWizard has already
    called server.begin() internally, so this is a no-op; the /config routes
    are already in place.
    Agent-Logs-Url: https://github.com/jrutlen/Choo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
    [main.cpp]
2026-04-14 Fix /config page going unreachable: remove NW.loop(), restart server on reconnect
    NW.loop() was calling _stopHTTP() (portal cleanup timeout) after ~3 minutes,
    which stopped the WebServer socket and made /config unreachable. Since we use
    NetWizardStrategy::BLOCKING, the entire portal session is handled inside
    autoConnect(); NW.loop() is not needed afterward. WiFi reconnection is
    handled natively by the ESP32 WiFi stack.
    Changes:
    - Remove NW.loop() from loop() and the while(!button[2]) sub-loop
    - Move server.begin() into the onConnectionStatus CONNECTED callback so
    the server socket is (re)opened whenever WiFi connects or reconnects,
    after the lwIP stack is guaranteed to be ready
    - Remove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
    [main.cpp]
2026-04-14 Fix state machine after story completion
    - State 3: sync dial[] with freshly-read lastDial[] to prevent stale
    values causing immediate false dialSet triggers that detach dial LED
    pins from the LEDC PWM channel and break the fade animation
    - resetHardwareState: replace global ChatGPTuino instance with
    std::unique_ptr; reassigning the pointer destroys the old object and
    creates a fresh one with _msgCount=0, clearing the previous story's
    message history from the API context
    - setup: print device name on boot via thermal printer
    Agent-Logs-Url: https://github.com/jrutlen/Choose-Your-Own-GPT/sessions/d23ef0c3-eb54-46be-b986-232c220d0f9a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
    [main.cpp]
2026-04-14 Restore logo, add OTA update and import/export to config portal
    - Logo: restore original style (size M, bold+inverse, dashes, centred)
    - Config portal: add Import/Export JSON section (client-side FileReader
    + fetch; exports download as cyogpt-config.json)
    - Config portal: add OTA Firmware Update section; POST to /ota/update
    streams binary to flash via Update library; static s_otaFailed flag
    preserves error across abort() boundary; flush()+delay before reboot
    - Refactor: extract initChatIfConfigured() helper used in all three
    chat init sites (WiFi connect, config save, story reset)
    Agent-Logs-Url: https://github.com/jrutlen/Choose-Your-Own-GPT/sessions/028f1803-7c12-46f7-b8d8-dfaf337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
    [main.cpp]
2026-04-15 Fix crash and model incompatibility with newer OpenAI models
    - Bundle ChatGPTuino locally in lib/ChatGPTuino/ with two fixes:
    - max_tokens → max_completion_tokens (required by gpt-5.x, o1, o3, etc.)
    - null-safe content check in putResponseInMsgArray: logs the API error
    string and returns 0 instead of calling strlen(nullptr) → hard fault
    - Add error.message to JSON filter for API error visibility
    - Remove external ChatGPTuino git dep from platformio.ini
    - Add null guard in sendToPrint() and state-8 printer.println call
    - Improve instructions prompt: explicitly forbid markdown/special chars
    Agent-Logs-Url: https://github.com/jrutlen/Choose-Your-Own-GPT/sessions/c4a47f06-3955-4d5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
    [config.cpp, main.cpp]
2026-04-15 Implement word-wrap for thermal printer output
    Agent-Logs-Url: https://github.com/jrutlen/Choose-Your-Own-GPT/sessions/8d34b501-e6f2-402c-bc0e-b4e2d35bc39c
2026-04-16 Fix String(pad, ' ') padding bug in printWrapped
    Agent-Logs-Url: https://github.com/jrutlen/Choose-Your-Own-GPT/sessions/f6c8bc03-c79f-4345-bd20-97f95ce14ab0
    [main.cpp]
2026-04-16 Disable printer.wake() calls
    Comment out printer.wake() to prevent printing 8
    [main.cpp]
